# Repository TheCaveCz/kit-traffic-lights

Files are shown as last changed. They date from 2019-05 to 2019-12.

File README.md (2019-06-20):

# Traffic Lights / Semafory

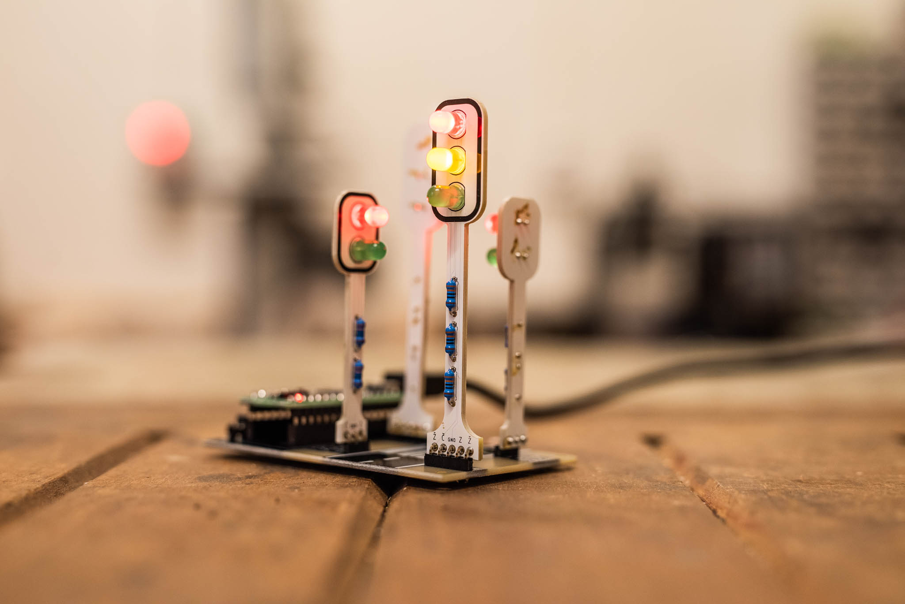
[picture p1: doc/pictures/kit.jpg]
kit


## Česky

Stavebnice přechodu pro chodce řízeného semafory. Tlačítko BTN1 dává signál pro chodce, tlačítko BTN3 vypne křižovatku.

* [Návod na stavbu](doc/manual-cz.md) ([PDF](doc/manual-cz.pdf))
* [Nahrání nového firmware](doc/firmware-cz.md)

## English

Coming coon...

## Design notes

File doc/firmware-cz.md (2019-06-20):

# Nahrání firmware

Arduina ve stavebnicích už mají program nahraný.

Kód je určený pro Arduino IDE. Pro nahrání do procesoru je nejprve potřeba nainstalovat knihovny [TaskScheduler](https://github.com/arkhipenko/TaskScheduler) a [OneButton](https://github.com/mathertel/OneButton).

Po nainstalování vyber v menu Tools (Nástroje) následující možnosti:

| Možnost | Hodnota |
| --- | --- |
| Board | Arduino Nano |
| Processor | ATmega328p |

Arduino připoj USB kabelem k počítači, vyber správný port a stiskni tlačítko upload.

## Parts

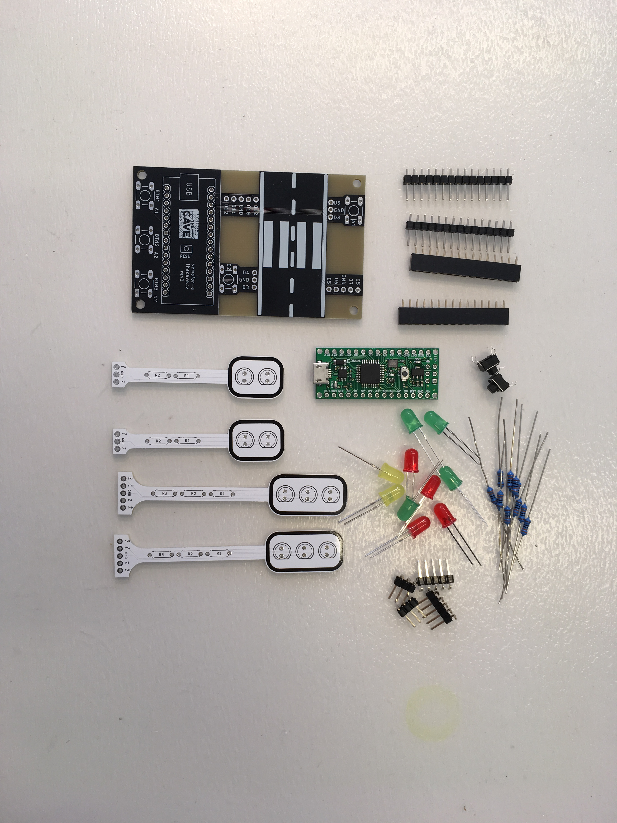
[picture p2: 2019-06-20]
doc/pictures/parts.jpg

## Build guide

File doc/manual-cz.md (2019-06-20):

# Návod na stavbu

[Stáhnout PDF](manual-cz.pdf)

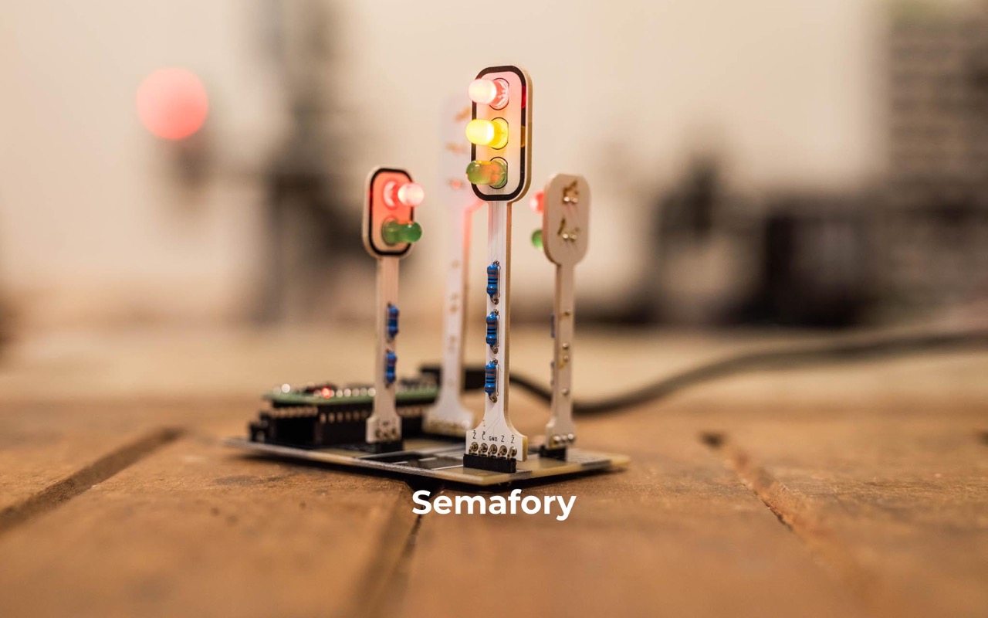
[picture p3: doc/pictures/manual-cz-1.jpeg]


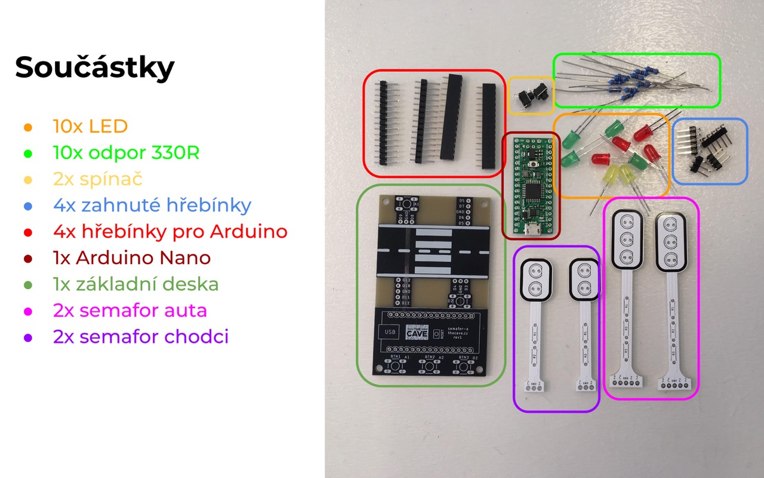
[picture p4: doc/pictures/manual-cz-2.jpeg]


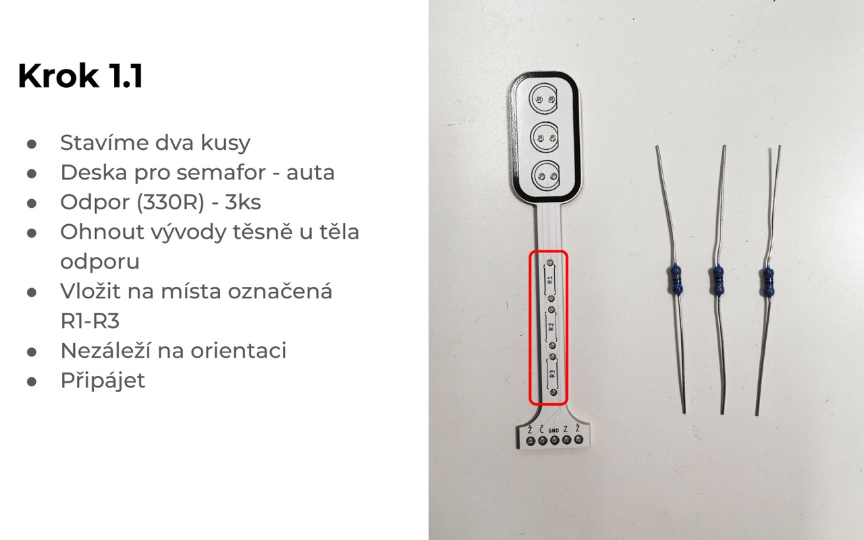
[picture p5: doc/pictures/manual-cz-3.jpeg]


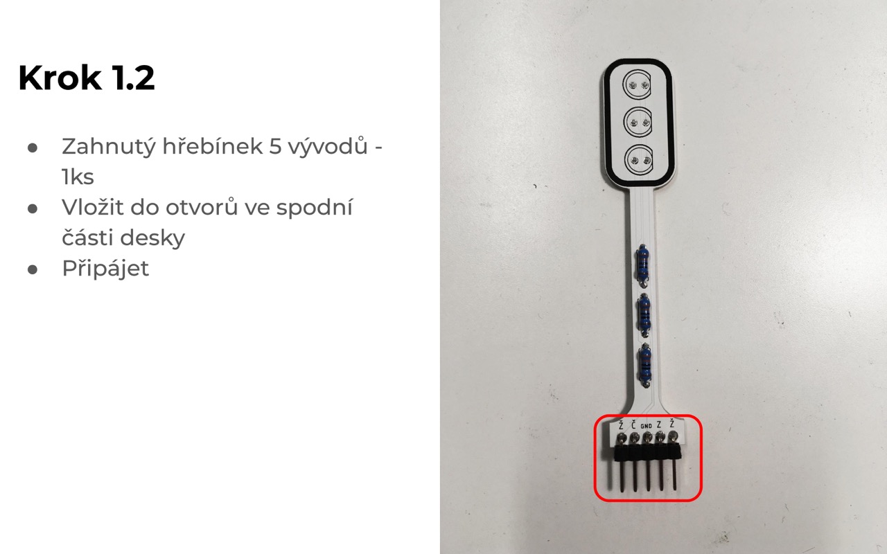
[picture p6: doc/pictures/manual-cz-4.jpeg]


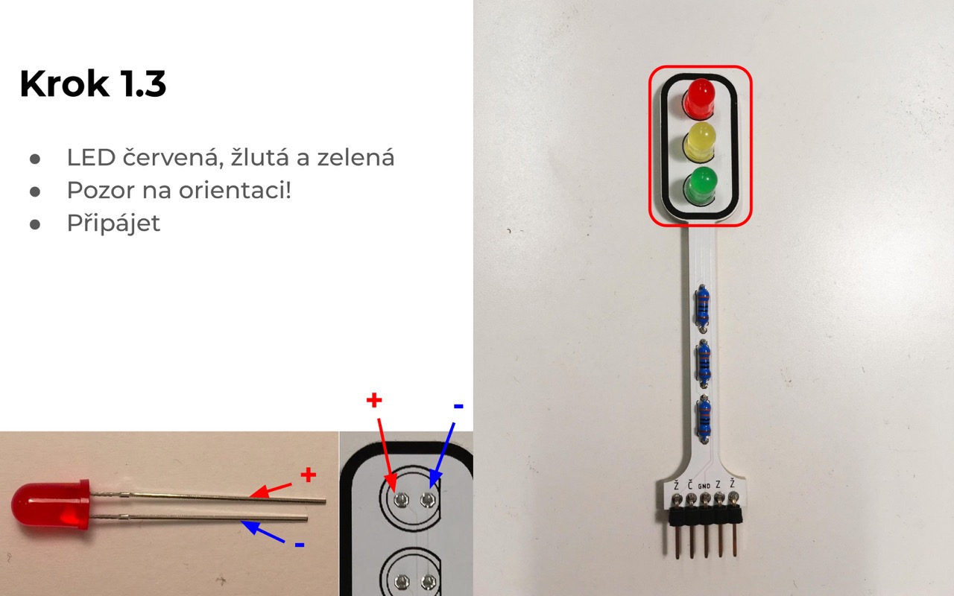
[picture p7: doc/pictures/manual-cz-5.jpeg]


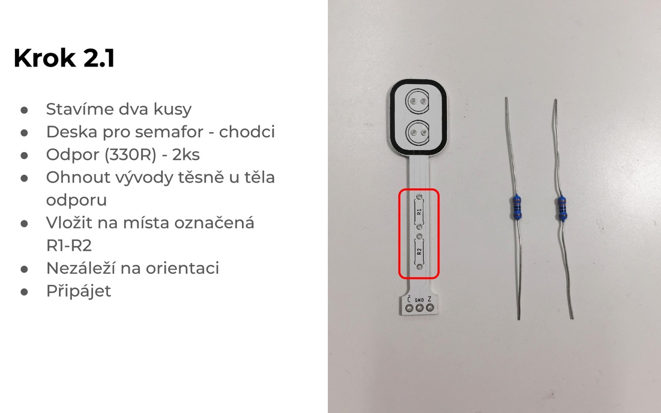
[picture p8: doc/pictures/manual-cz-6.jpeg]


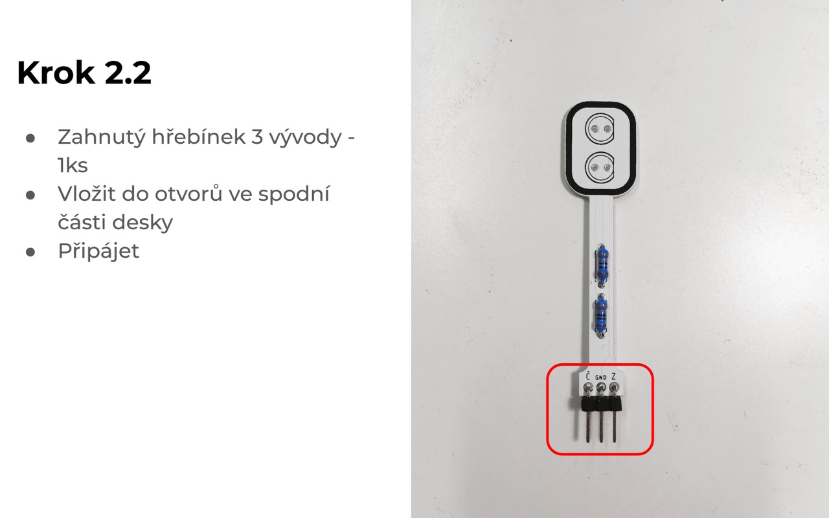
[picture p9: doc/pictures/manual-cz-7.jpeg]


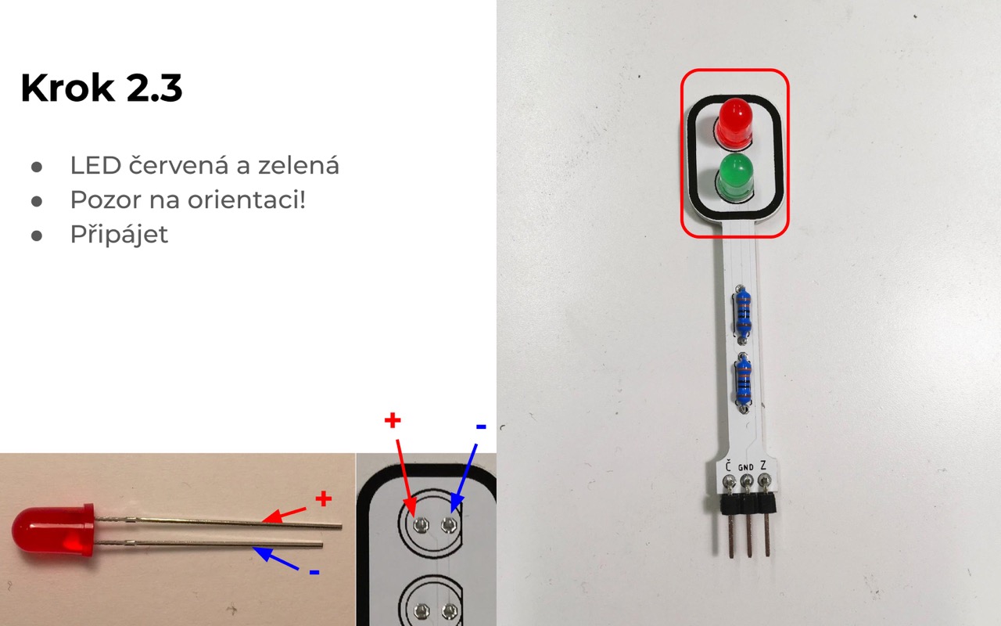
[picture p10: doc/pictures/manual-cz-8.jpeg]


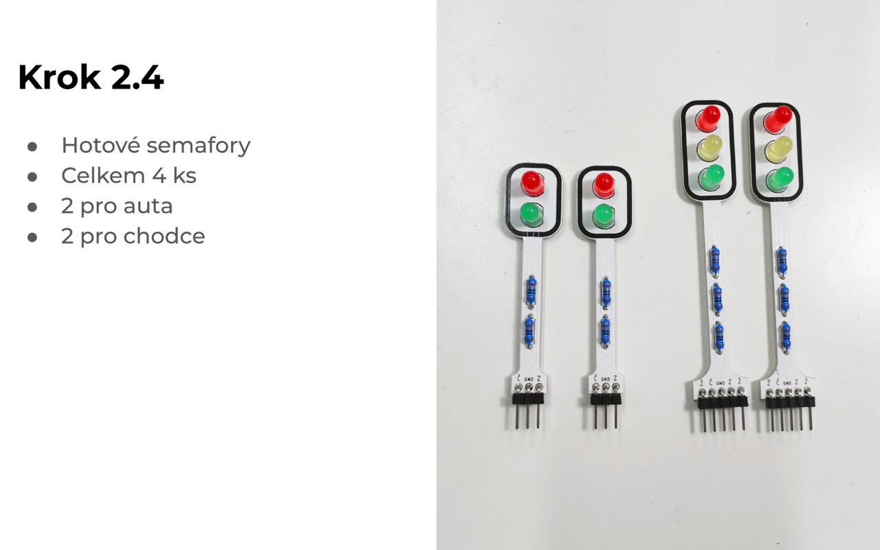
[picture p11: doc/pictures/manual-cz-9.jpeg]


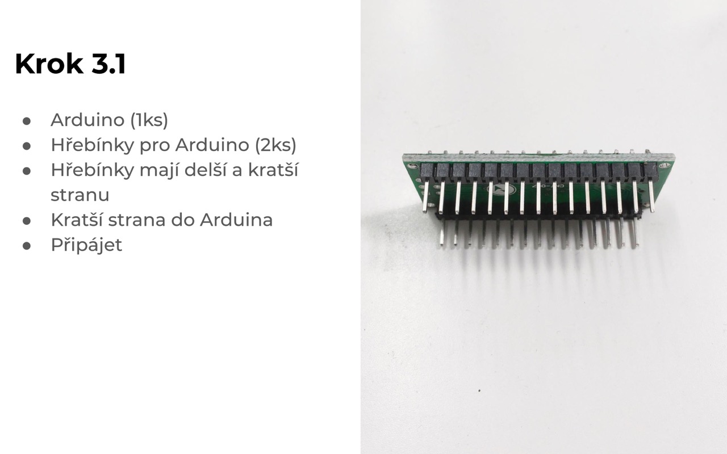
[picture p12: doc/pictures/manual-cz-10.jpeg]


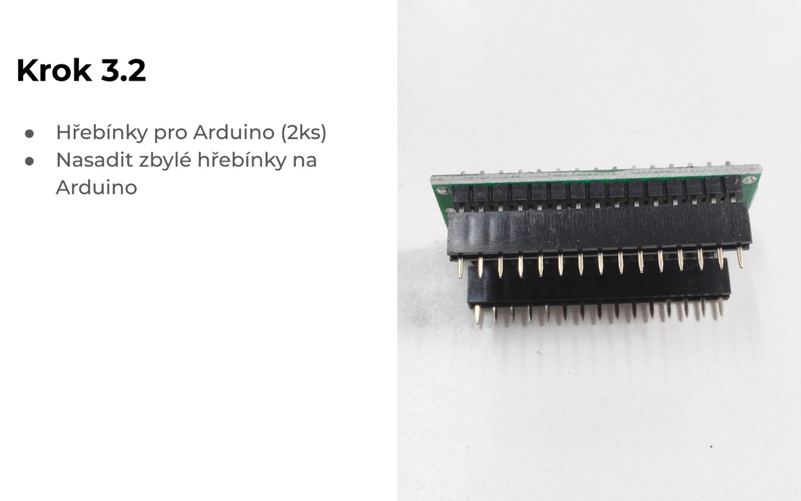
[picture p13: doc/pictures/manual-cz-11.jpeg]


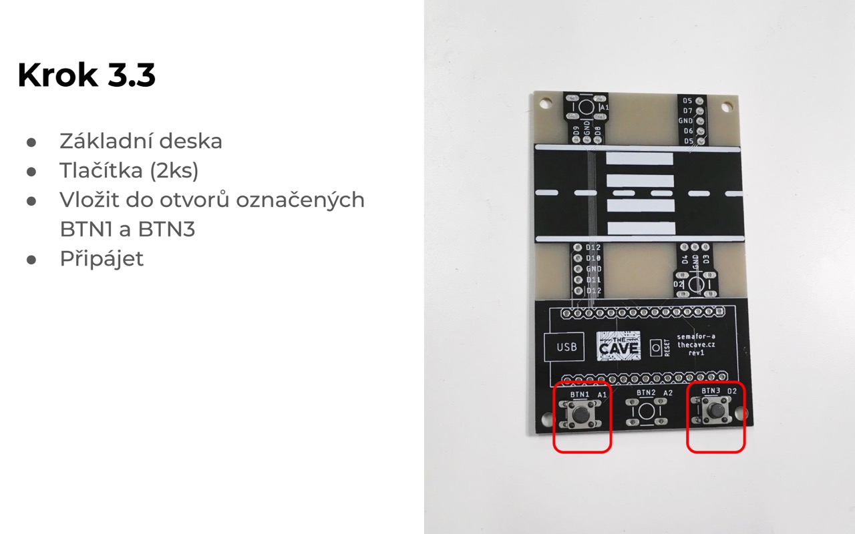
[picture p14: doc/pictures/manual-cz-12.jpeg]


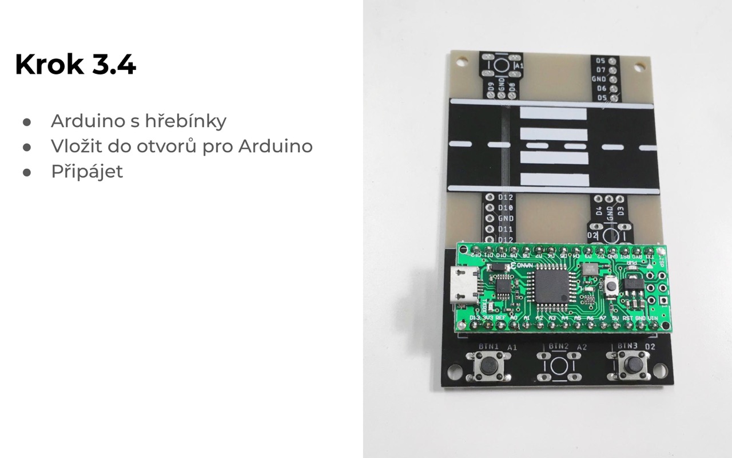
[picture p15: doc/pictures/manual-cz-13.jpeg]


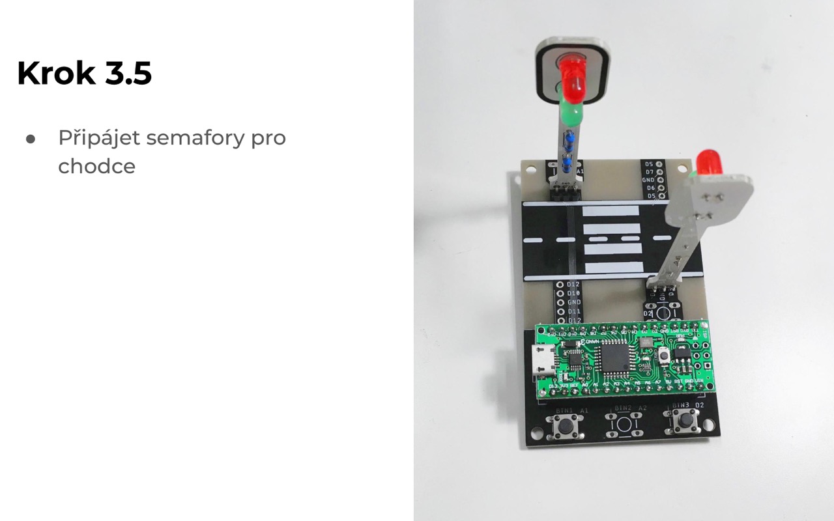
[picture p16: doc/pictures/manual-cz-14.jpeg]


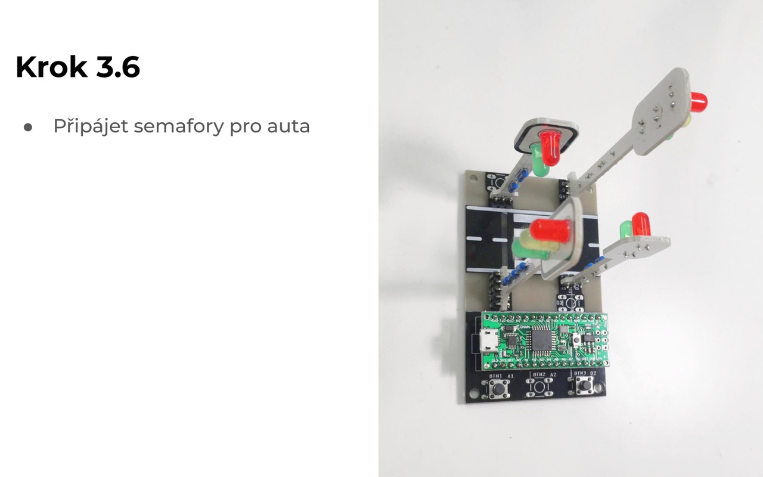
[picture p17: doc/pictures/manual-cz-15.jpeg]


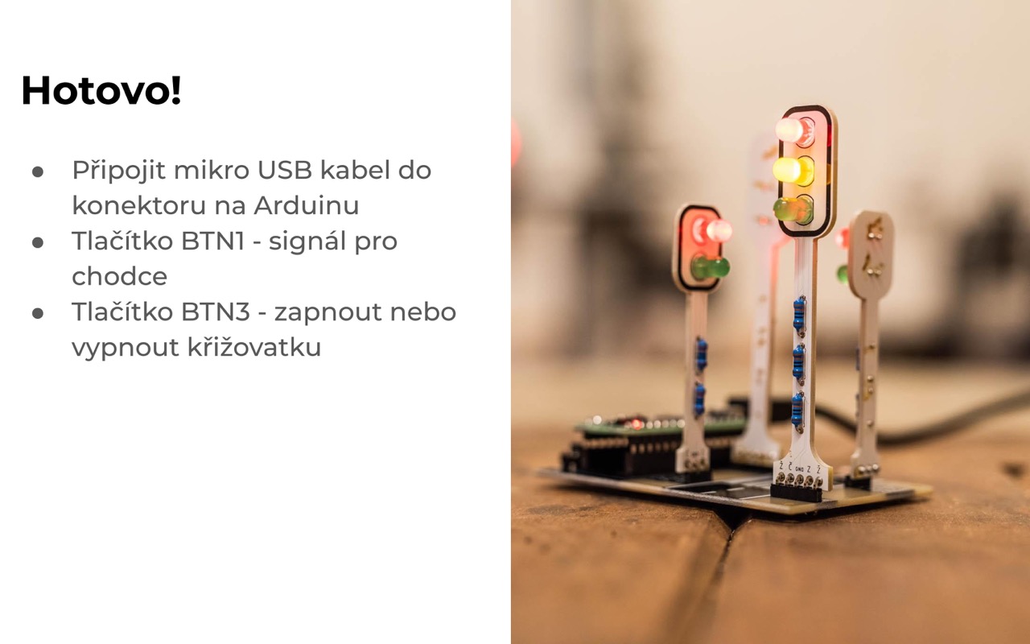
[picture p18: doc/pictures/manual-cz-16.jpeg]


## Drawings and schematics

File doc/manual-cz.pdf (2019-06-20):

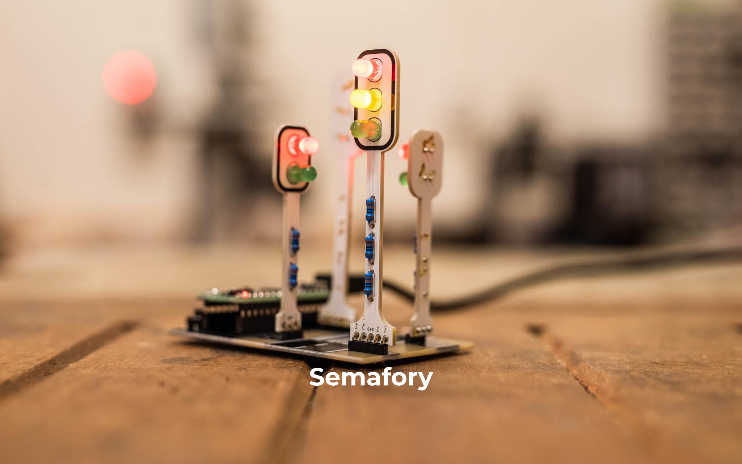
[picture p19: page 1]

Semafory

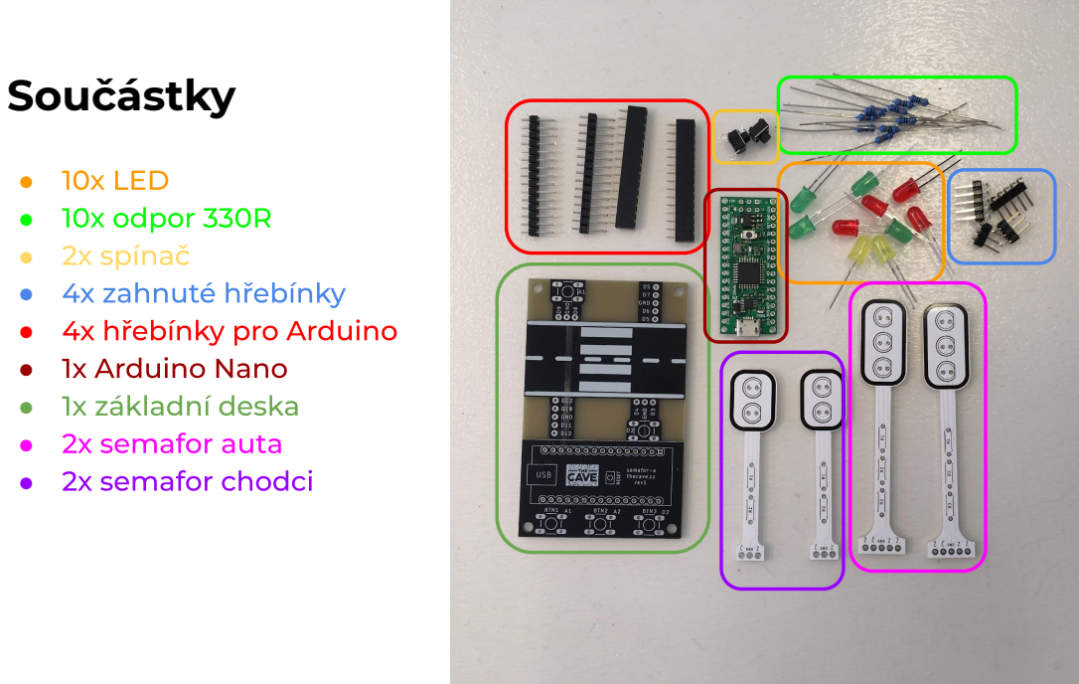
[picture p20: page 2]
Součástky

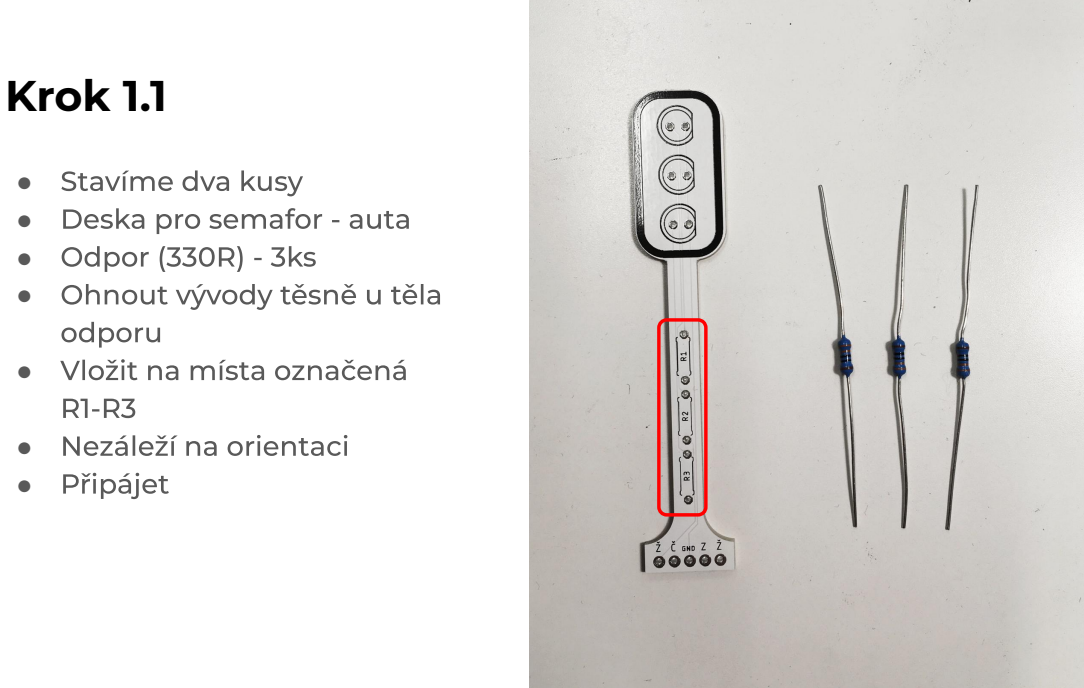
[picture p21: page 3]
Krok 1.1

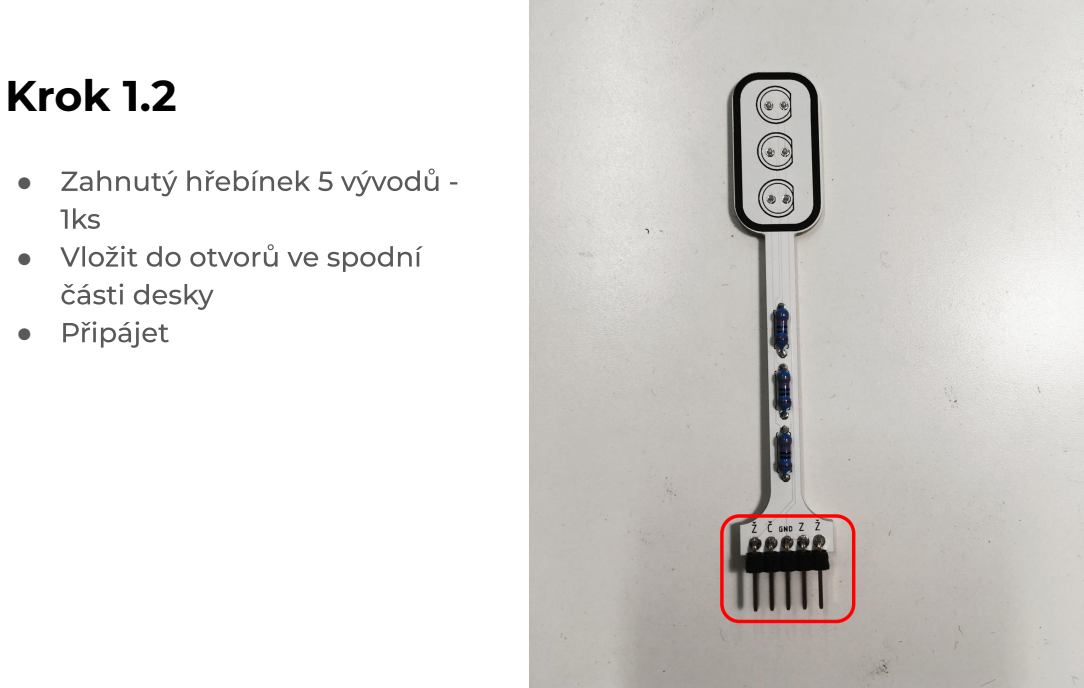
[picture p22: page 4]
Krok 1.2

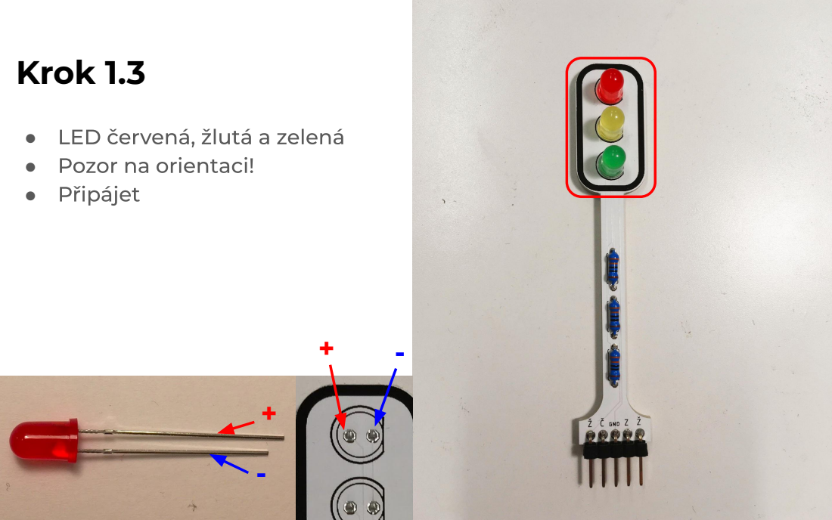
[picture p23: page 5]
Krok 1.3

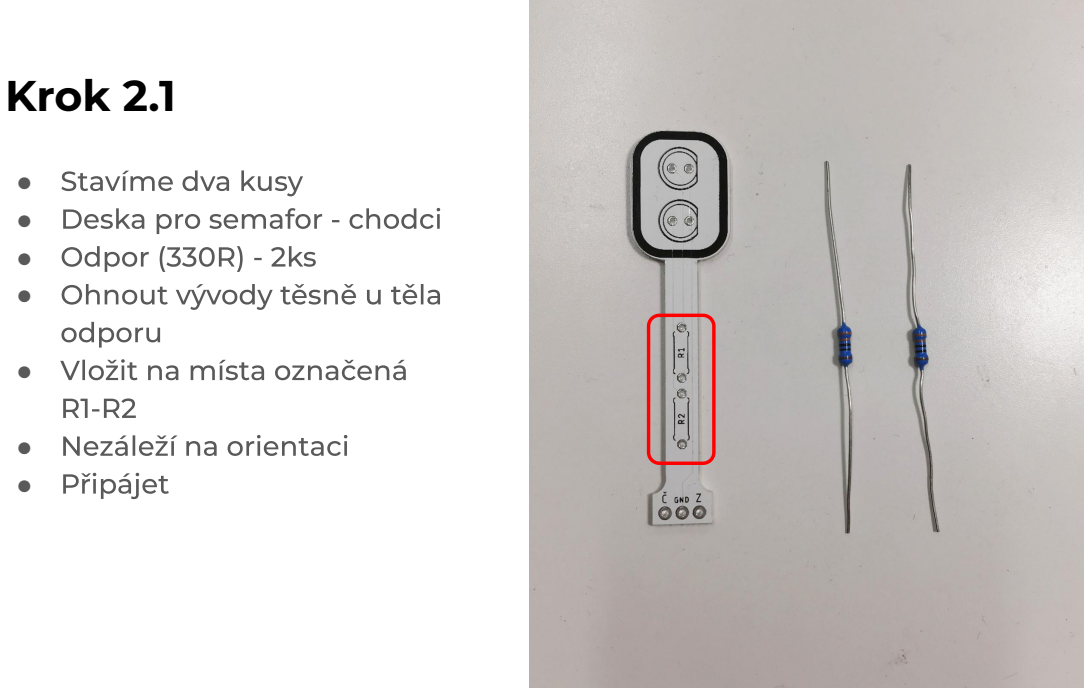
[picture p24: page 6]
Krok 2.1

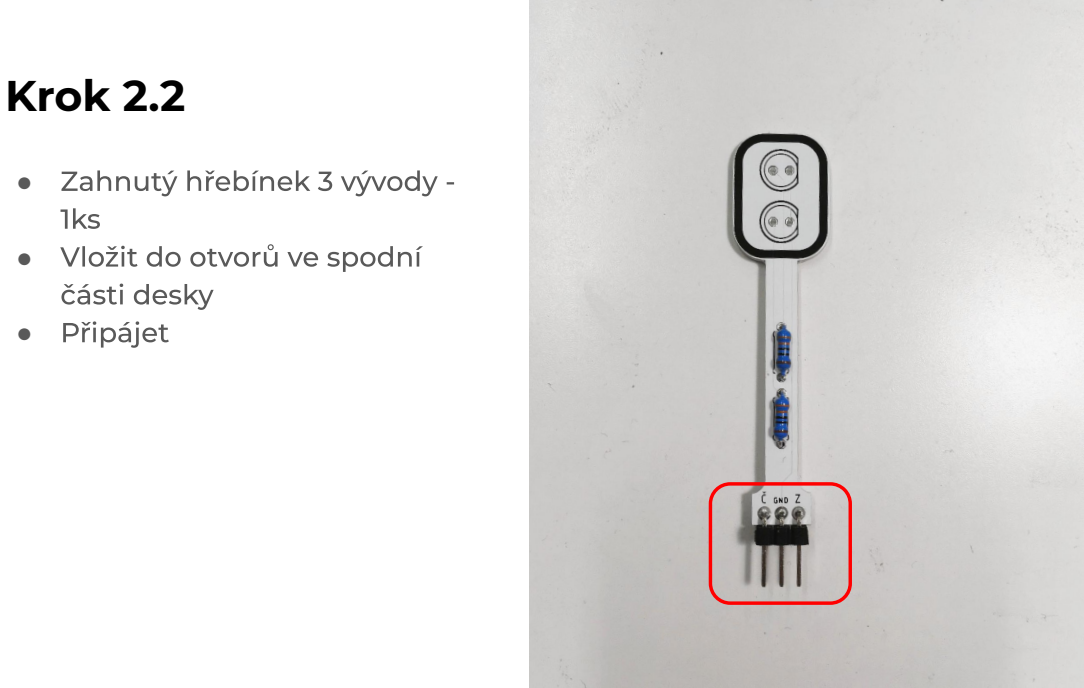
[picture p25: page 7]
Krok 2.2

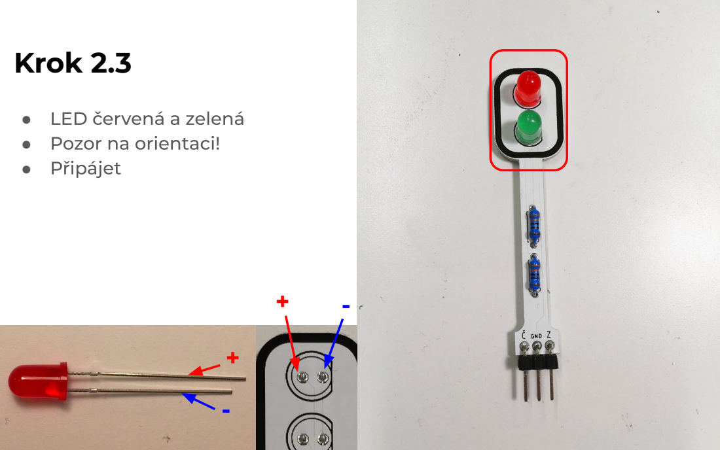
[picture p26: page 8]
Krok 2.3

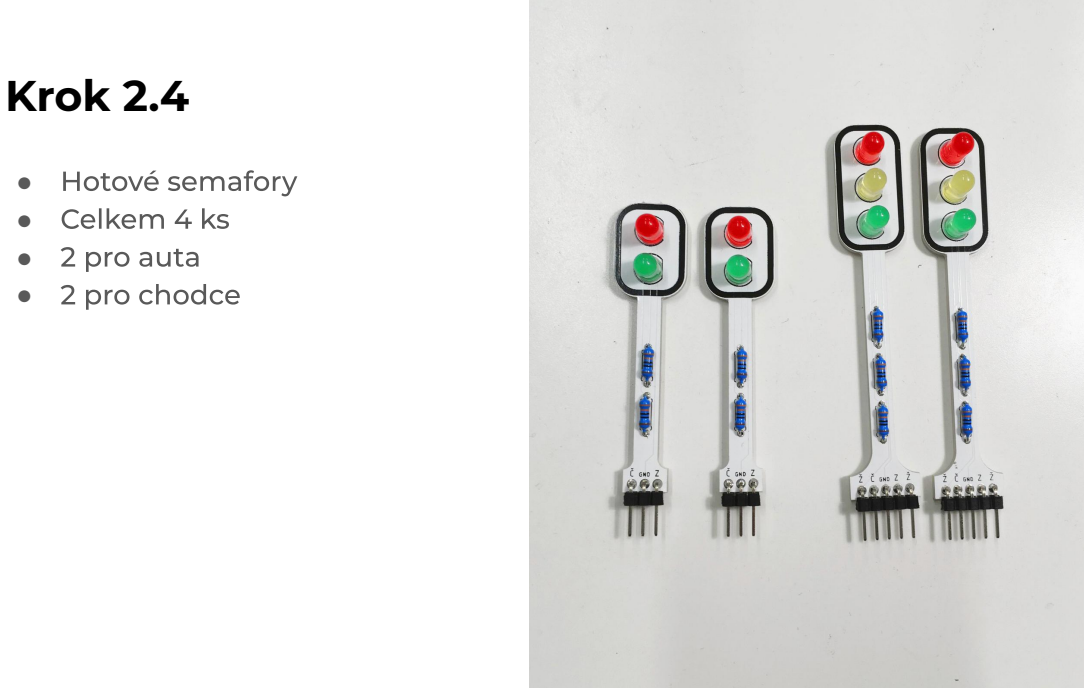
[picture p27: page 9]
Krok 2.4

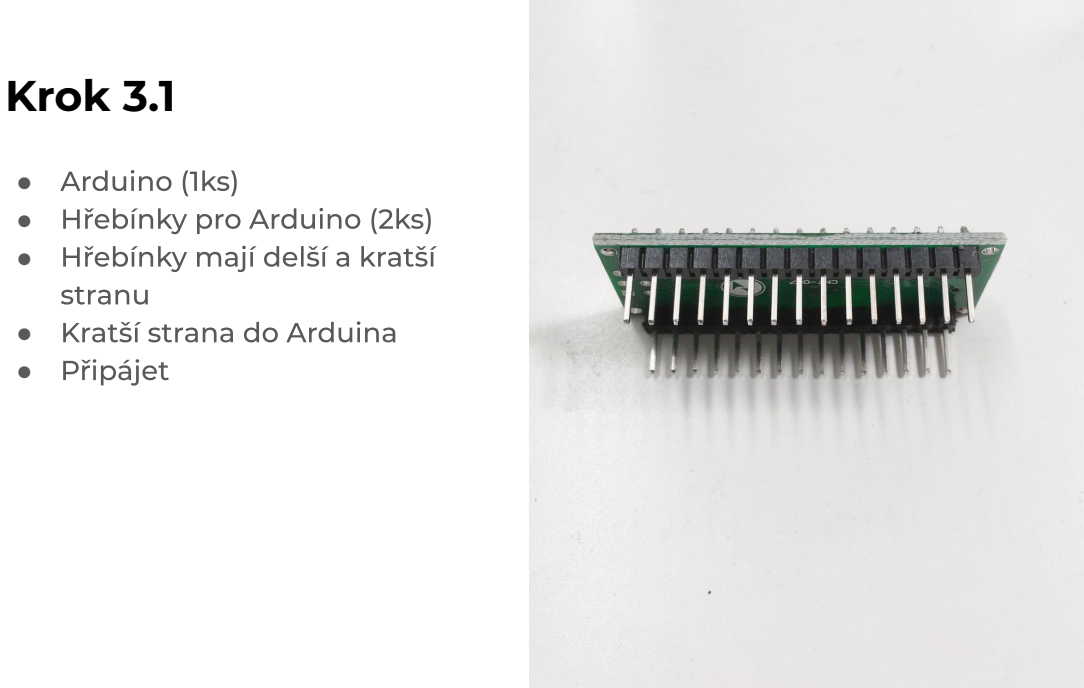
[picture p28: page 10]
Krok 3.1

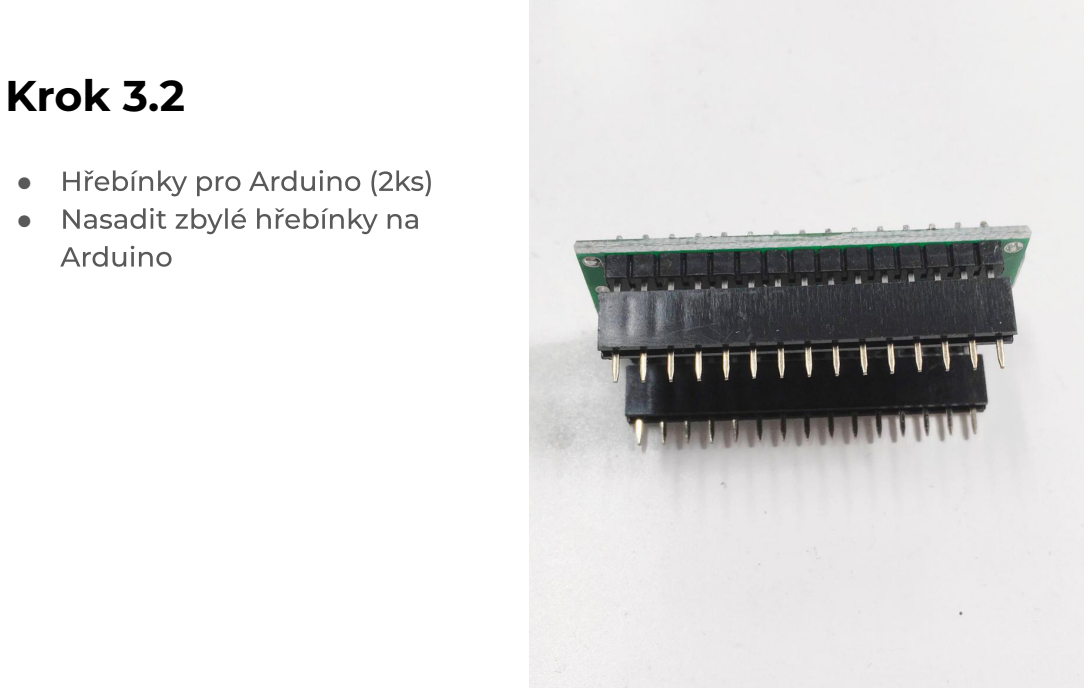
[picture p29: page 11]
Krok 3.2

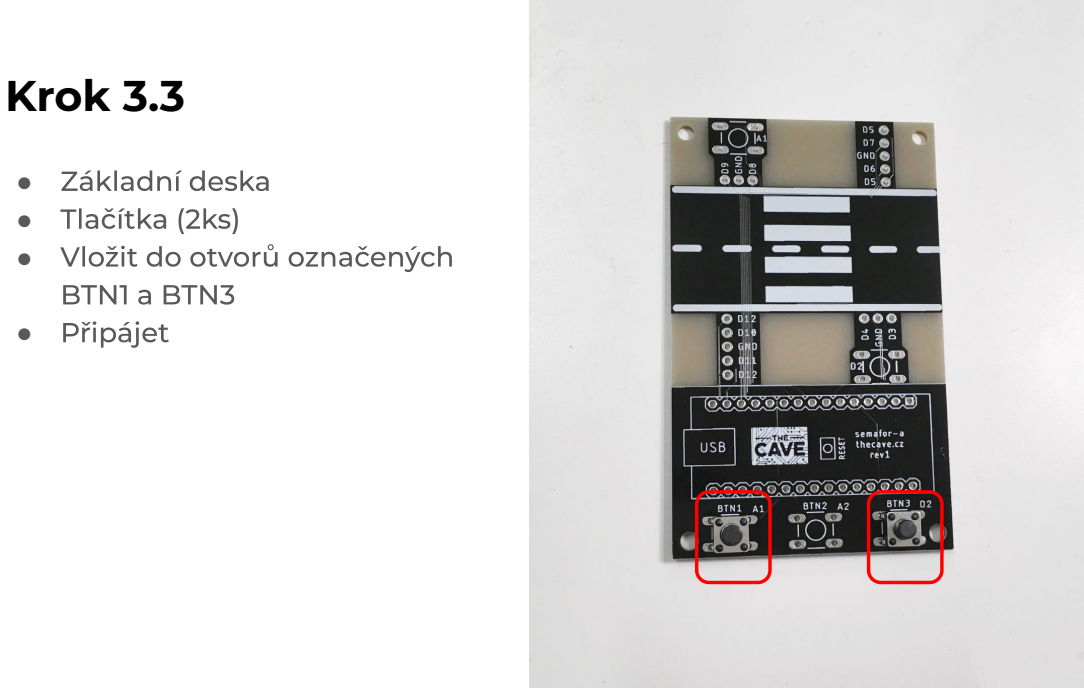
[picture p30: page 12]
Krok 3.3

Krok 3.4

Krok 3.5

Krok 3.6

Hotovo!


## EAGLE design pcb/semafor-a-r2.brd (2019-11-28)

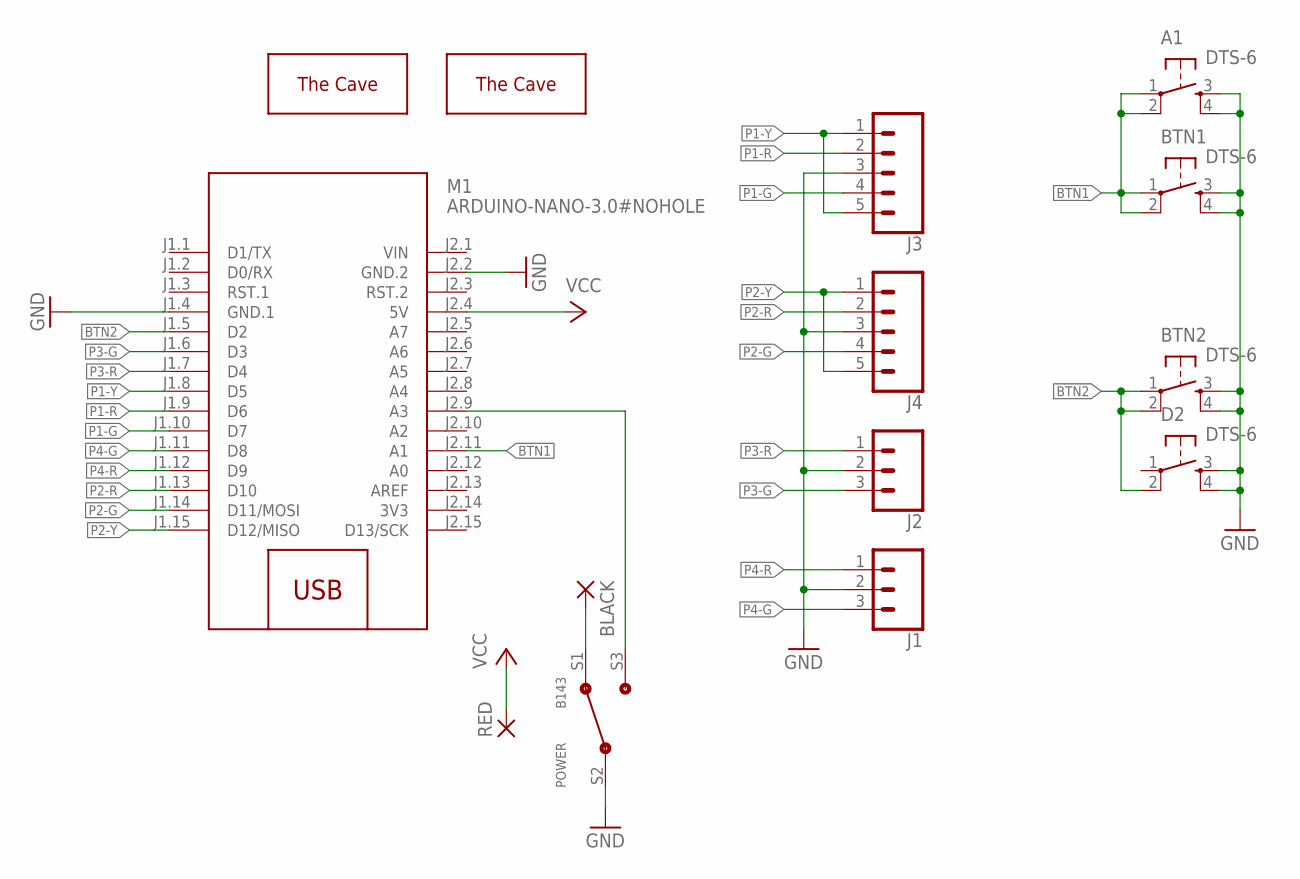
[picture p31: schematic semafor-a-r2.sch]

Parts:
A1: DTS-6
BLACK: WIREPAD2,54/1,0; 2,54/1,0
BTN1, BTN2: DTS-6
D2: DTS-6
J1, J2: CONN_031X03_NO_SILK; 1X03_NO_SILK
J3, J4: CONN_05NO_SILK; 1X05_NO_SILK
M1: ARDUINO-NANO-3.0#NOHOLE; ARDUINO-NANO-3.0
POWER: B143
RED: WIREPAD2,54/1,0; 2,54/1,0
U$1: THECAVE_LOGO_NEW_TOP_SMALL; NEW_LOGO_SMALL_TOP
U$2: THECAVE_LOGO_NEW_BOTTOM; NEW_LOGO_BOTTOM

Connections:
3V3: M1.J2.14 (3V3)
BTN1: A1.1, A1.2, BTN1.1, BTN1.2, M1.J2.11 (A1)
BTN2: BTN2.1, BTN2.2, D2.2, M1.J1.5 (D2)
GND: A1.3, A1.4, BTN1.3, BTN1.4, BTN2.3, BTN2.4, D2.3, D2.4, J1.2, J2.2, J3.3, J4.3, M1.J1.4 (GND.1), M1.J2.2 (GND.2), POWER.S2 (COM)
unnamed: M1.J2.9 (A3), POWER.S3 (S2)
unnamed: BLACK.1, POWER.S1
P1-G: J3.4, M1.J1.10 (D7)
P1-R: J3.2, M1.J1.9 (D6)
P1-Y: J3.1, J3.5, M1.J1.8 (D5)
P2-G: J4.4, M1.J1.14 (D11/MOSI)
P2-R: J4.2, M1.J1.13 (D10)
P2-Y: J4.1, J4.5, M1.J1.15 (D12/MISO)
P3-G: J2.3, M1.J1.6 (D3)
P3-R: J2.1, M1.J1.7 (D4)
P4-G: J1.3, M1.J1.11 (D8)
P4-R: J1.1, M1.J1.12 (D9)
VCC: M1.J2.4 (5V), RED.1
VIN: M1.J2.1 (VIN)

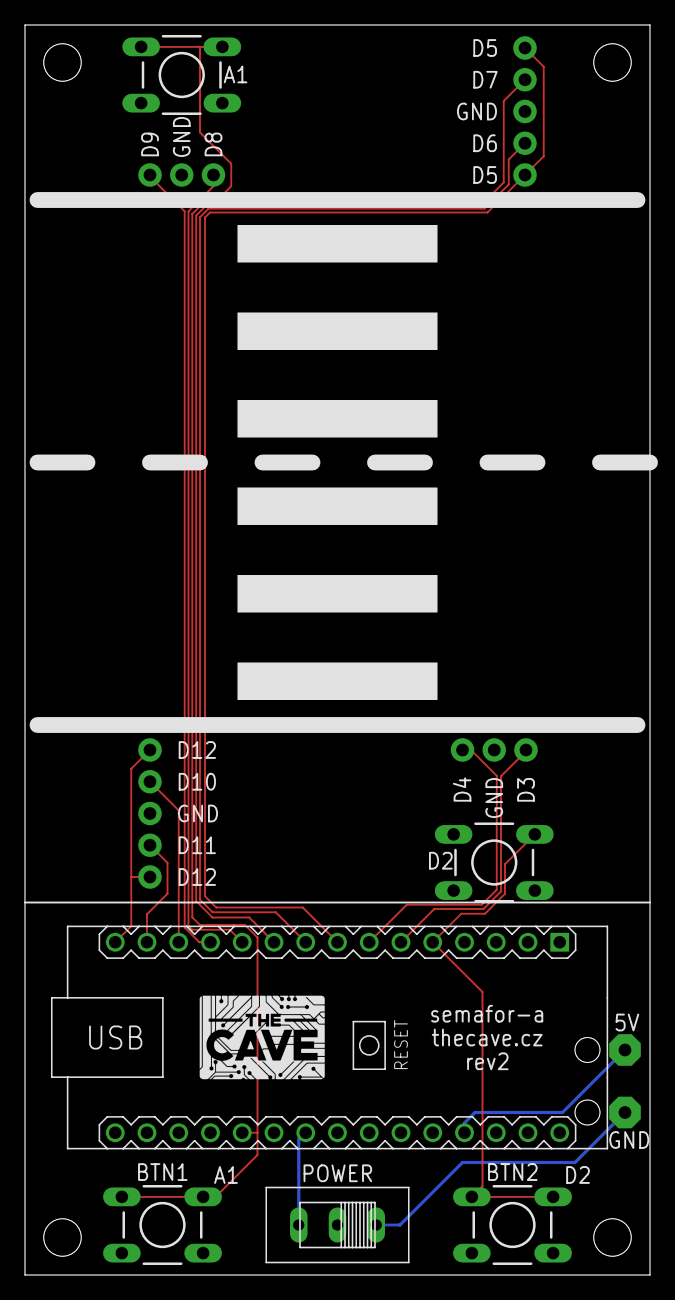
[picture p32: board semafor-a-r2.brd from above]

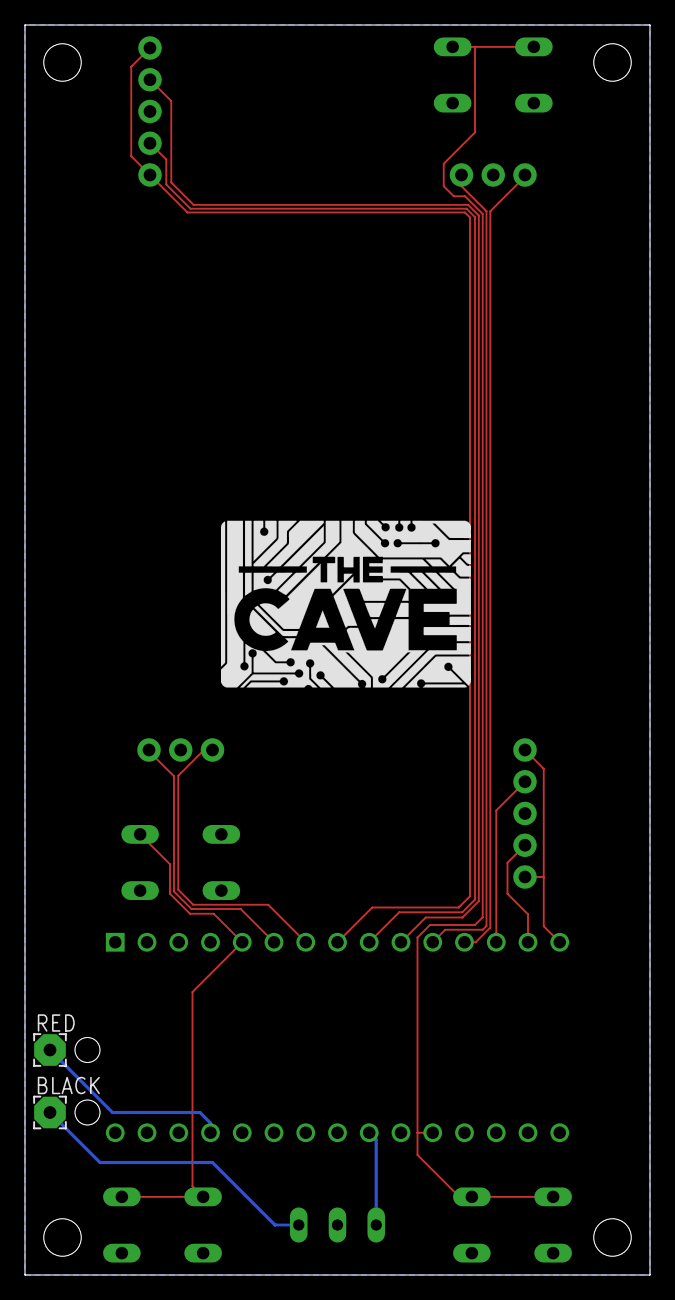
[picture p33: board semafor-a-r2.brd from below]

Board: 2 copper layers, 50.0 x 100.0 mm, 14 parts (2 on the bottom side), 16 nets.

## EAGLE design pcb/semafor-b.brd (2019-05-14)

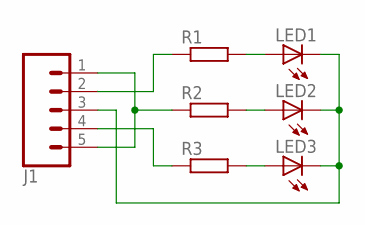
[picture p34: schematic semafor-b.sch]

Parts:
J1: CONN_05NO_SILK; 1X05_NO_SILK
LED1, LED2, LED3: LED5MM
R1, R2, R3: R-EU_0207/7; 0207/7

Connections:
unnamed: LED3.A, R3.2
unnamed: LED2.A, R2.2
unnamed: LED1.A, R1.2
unnamed: J1.3, LED1.K (C), LED2.K (C), LED3.K (C)
unnamed: J1.2, R1.1
unnamed: J1.4, R3.1
unnamed: J1.1, J1.5, R2.1

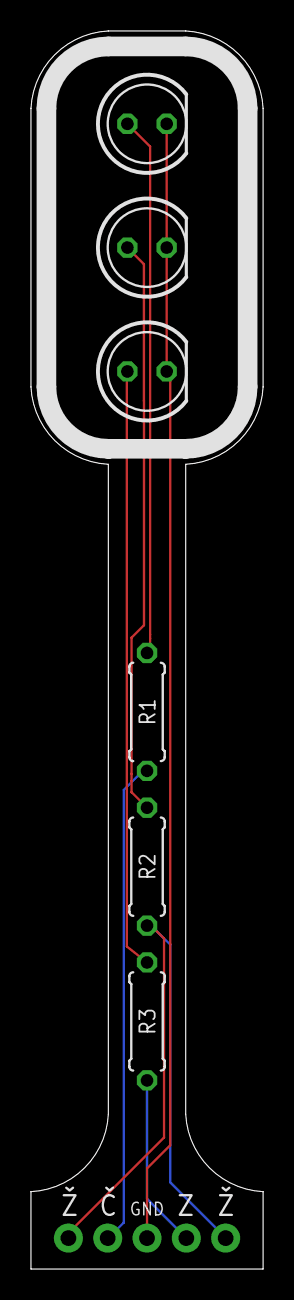
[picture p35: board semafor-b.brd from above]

Board: 2 copper layers, 15.0 x 80.0 mm, 7 parts (0 on the bottom side), 7 nets.

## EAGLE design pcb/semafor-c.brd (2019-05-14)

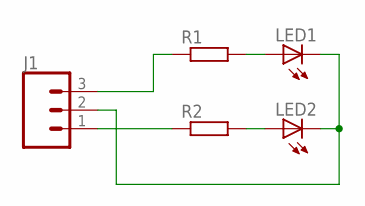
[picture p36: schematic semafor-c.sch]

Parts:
J1: CONN_031X03_NO_SILK; 1X03_NO_SILK
LED1, LED2: LED5MM
R1, R2: R-EU_0207/7; 0207/7

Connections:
unnamed: LED2.A, R2.2
unnamed: LED1.A, R1.2
unnamed: J1.2, LED1.K (C), LED2.K (C)
unnamed: J1.3, R1.1
unnamed: J1.1, R2.1

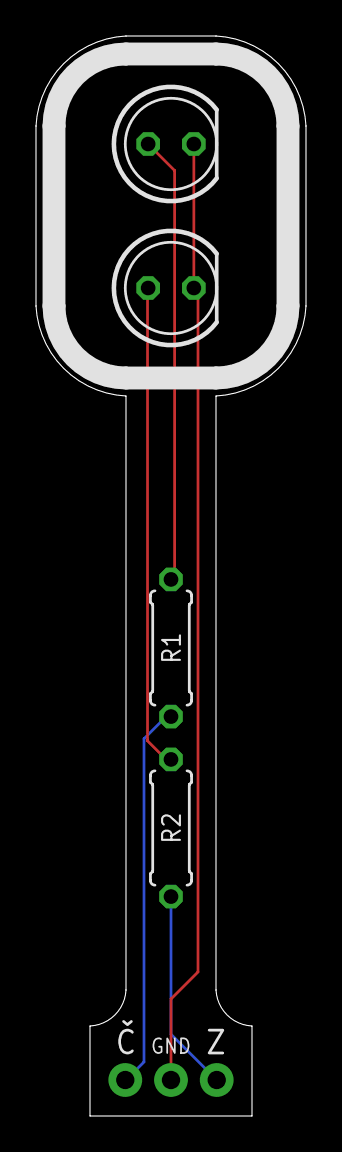
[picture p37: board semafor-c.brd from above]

Board: 2 copper layers, 15.0 x 60.0 mm, 5 parts (0 on the bottom side), 5 nets.

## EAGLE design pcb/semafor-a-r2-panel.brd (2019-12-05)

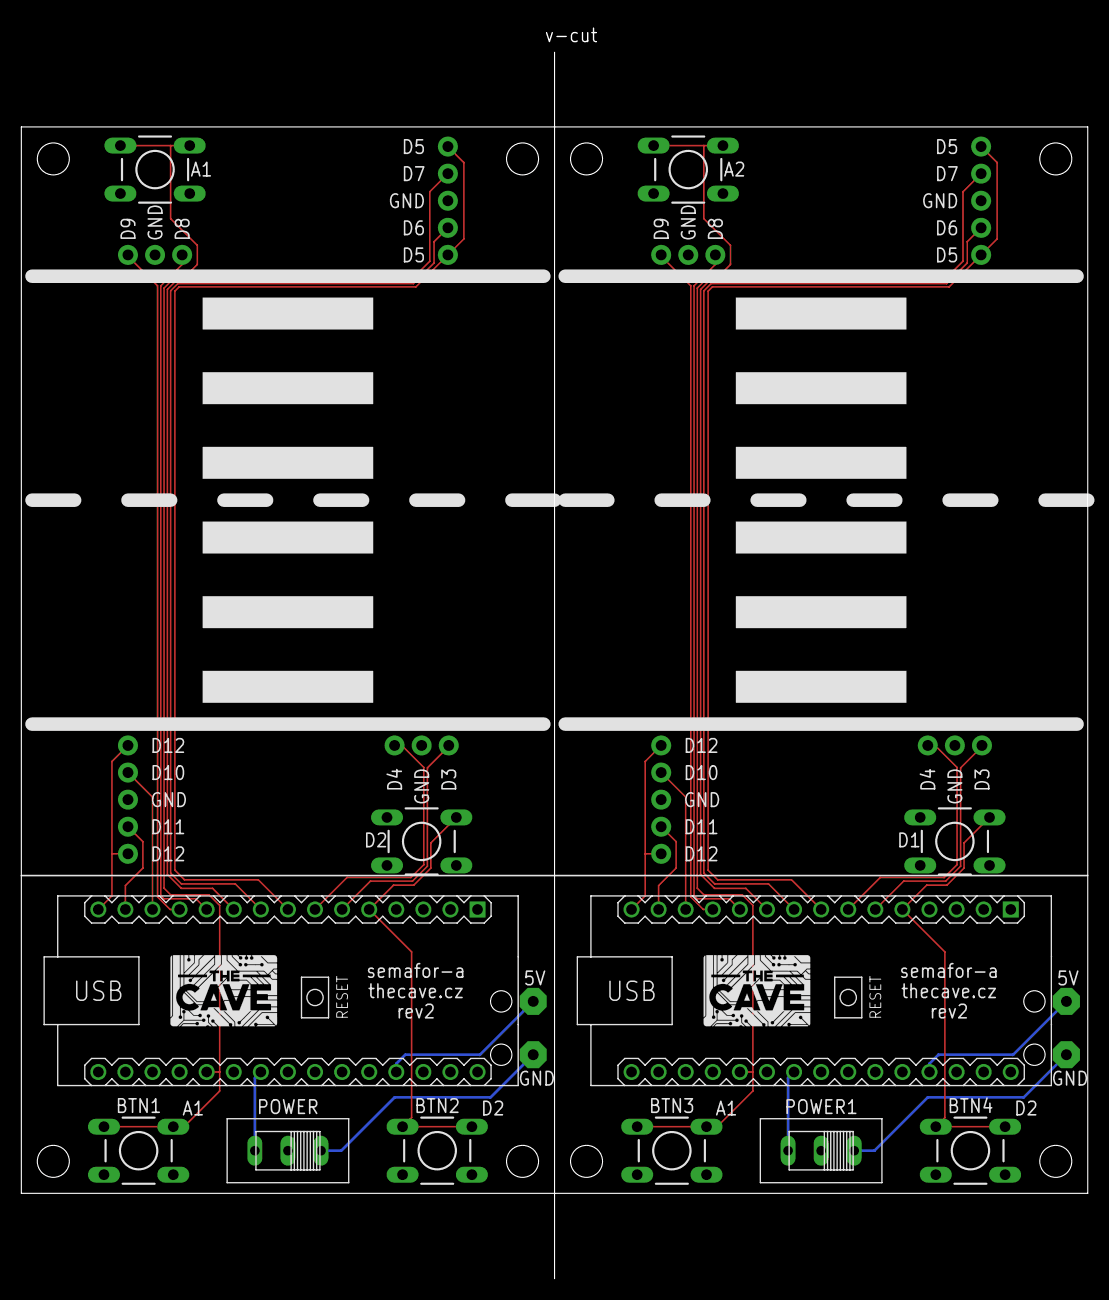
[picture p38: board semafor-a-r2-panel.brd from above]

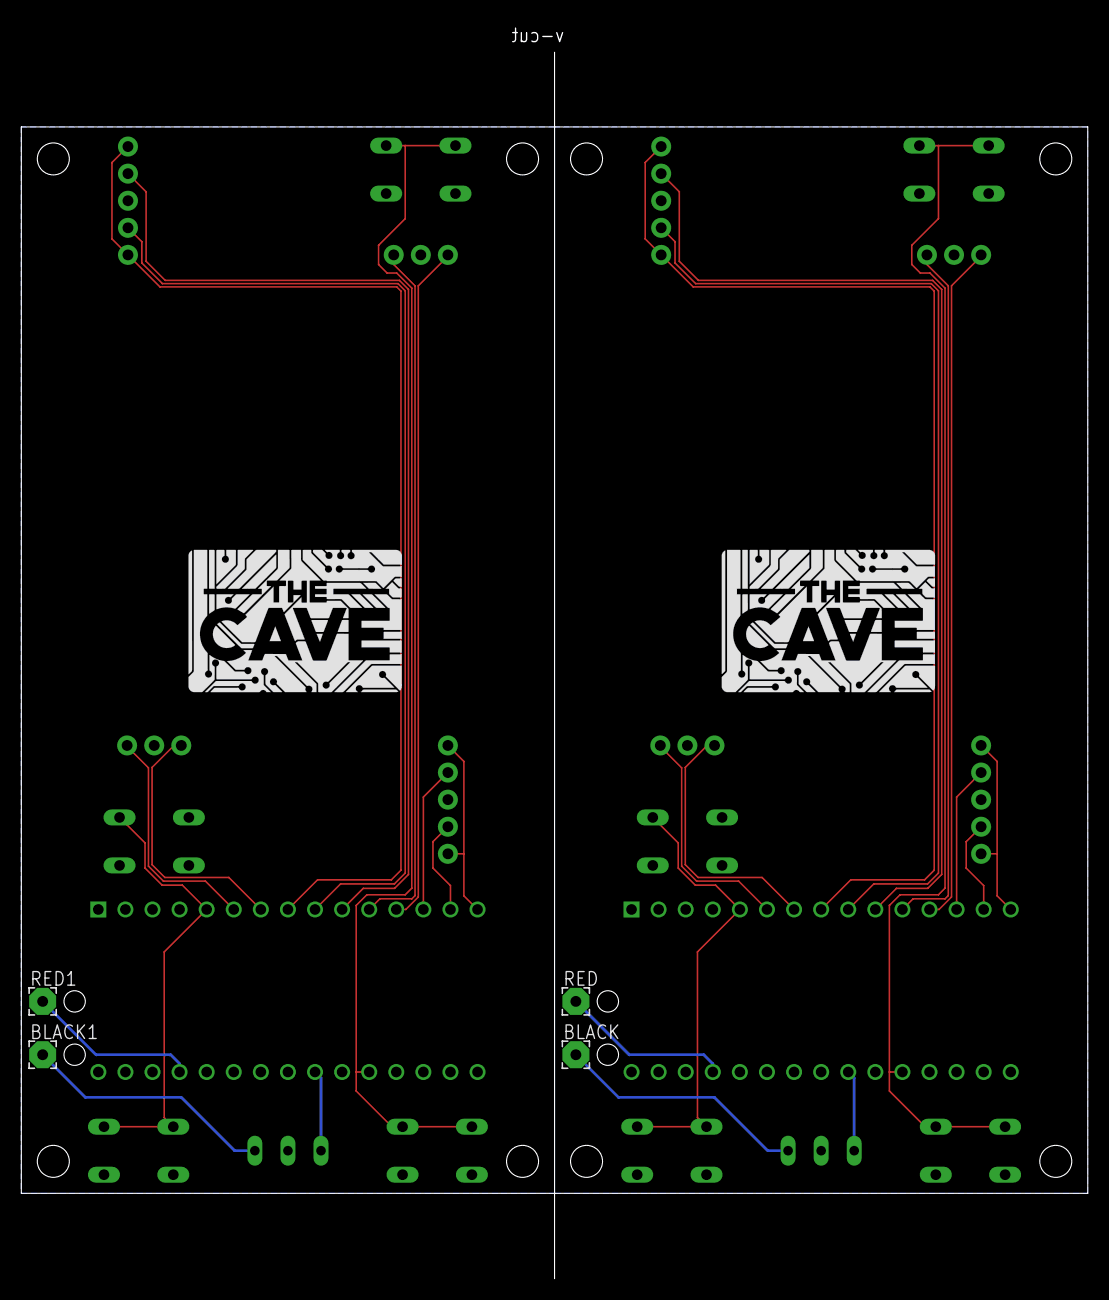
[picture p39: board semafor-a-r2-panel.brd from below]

Board: 2 copper layers, 100.0 x 100.0 mm, 28 parts (4 on the bottom side), 32 nets.

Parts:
A1, A2: DTS-6
BLACK, BLACK1: 2,54/1,0
BTN1, BTN2, BTN3, BTN4: DTS-6
D1, D2: DTS-6
J1, J2, J5, J6: 1X03_NO_SILK
J3, J4, J7, J8: 1X05_NO_SILK
M1, M2: ARDUINO-NANO-3.0#NOHOLE; ARDUINO-NANO-3.0
POWER, POWER1: B143
RED, RED1: 2,54/1,0
U$1, U$3: THECAVE_LOGO_NEW_TOP_SMALL; NEW_LOGO_SMALL_TOP
U$2, U$4: THECAVE_LOGO_NEW_BOTTOM; NEW_LOGO_BOTTOM

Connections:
BTN1: A1.1, A1.2, BTN1.1, BTN1.2, M1.J2.11
BTN2: BTN2.1, BTN2.2, D2.2, M1.J1.5
BTN3: A2.1, A2.2, BTN3.1, BTN3.2, M2.J2.11
BTN4: BTN4.1, BTN4.2, D1.2, M2.J1.5
GND: A1.3, A1.4, BTN1.3, BTN1.4, BTN2.3, BTN2.4, D2.3, D2.4, J1.2, J2.2, J3.3, J4.3, M1.J1.4, M1.J2.2, POWER.S2
GND1: A2.3, A2.4, BTN3.3, BTN3.4, BTN4.3, BTN4.4, D1.3, D1.4, J5.2, J6.2, J7.3, J8.3, M2.J1.4, M2.J2.2, POWER1.S2
unnamed: M1.J2.9, POWER.S3
unnamed: BLACK.1, POWER.S1
unnamed: M2.J2.9, POWER1.S3
unnamed: BLACK1.1, POWER1.S1
P1-G: J3.4, M1.J1.10
P1-G1: J7.4, M2.J1.10
P1-R: J3.2, M1.J1.9
P1-R1: J7.2, M2.J1.9
P1-Y: J3.1, J3.5, M1.J1.8
P1-Y1: J7.1, J7.5, M2.J1.8
P2-G: J4.4, M1.J1.14
P2-G1: J8.4, M2.J1.14
P2-R: J4.2, M1.J1.13
P2-R1: J8.2, M2.J1.13
P2-Y: J4.1, J4.5, M1.J1.15
P2-Y1: J8.1, J8.5, M2.J1.15
P3-G: J2.3, M1.J1.6
P3-G1: J6.3, M2.J1.6
P3-R: J2.1, M1.J1.7
P3-R1: J6.1, M2.J1.7
P4-G: J1.3, M1.J1.11
P4-G1: J5.3, M2.J1.11
P4-R: J1.1, M1.J1.12
P4-R1: J5.1, M2.J1.12
VCC: M1.J2.4, RED.1
VCC1: M2.J2.4, RED1.1

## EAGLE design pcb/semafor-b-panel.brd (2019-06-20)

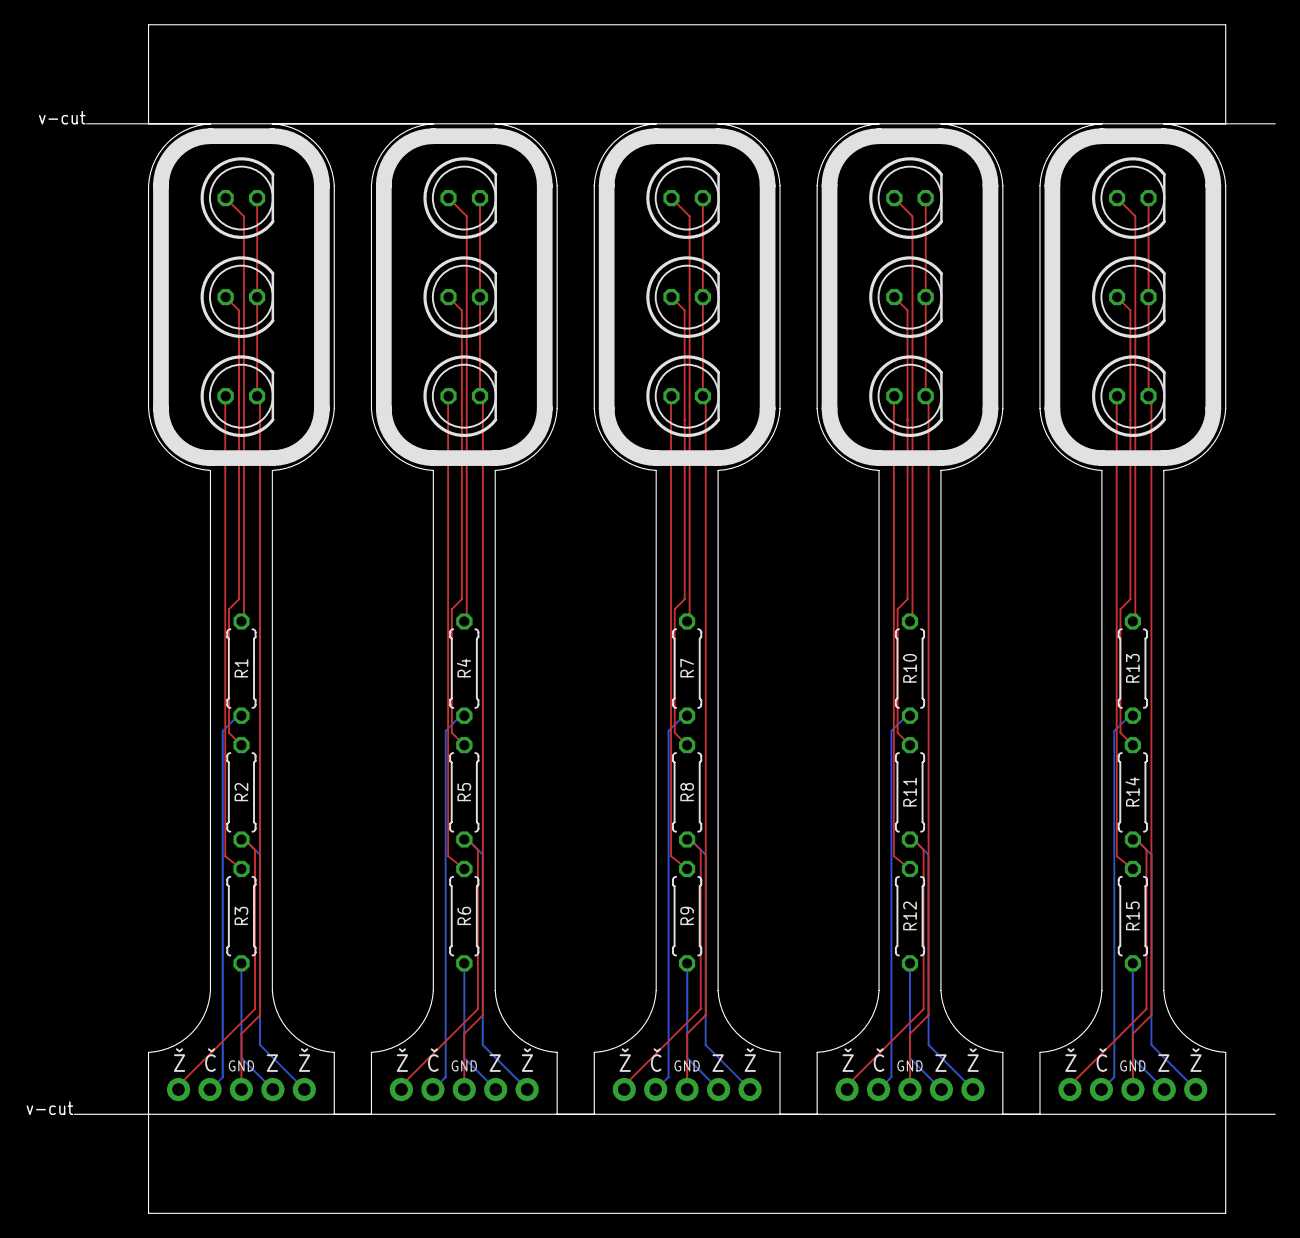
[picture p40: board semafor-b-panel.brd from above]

Board: 2 copper layers, 87.0 x 96.0 mm, 35 parts (0 on the bottom side), 35 nets.

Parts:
J1, J2, J3, J4, J5: 1X05_NO_SILK
LED1, LED2, LED3, LED4, LED5, LED6, LED7, LED8, LED9, LED10, LED11, LED12, LED13, LED14, LED15: LED5MM
R1, R2, R3, R4, R5, R6, R7, R8, R9, R10, R11, R12, R13, R14, R15: 0207/7

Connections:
unnamed: LED3.A, R3.2
unnamed: LED2.A, R2.2
unnamed: LED1.A, R1.2
unnamed: J1.3, LED1.K, LED2.K, LED3.K
unnamed: J1.2, R1.1
unnamed: J1.4, R3.1
unnamed: J1.1, J1.5, R2.1
unnamed: J2.3, LED4.K, LED5.K, LED6.K
unnamed: J2.2, R4.1
unnamed: J2.4, R6.1
unnamed: J2.1, J2.5, R5.1
unnamed: LED6.A, R6.2
unnamed: LED5.A, R5.2
unnamed: LED4.A, R4.2
unnamed: J3.3, LED7.K, LED8.K, LED9.K
unnamed: J3.2, R7.1
unnamed: J3.4, R9.1
unnamed: J3.1, J3.5, R8.1
unnamed: LED9.A, R9.2
unnamed: LED8.A, R8.2
unnamed: LED7.A, R7.2
unnamed: J4.3, LED10.K, LED11.K, LED12.K
unnamed: J4.2, R10.1
unnamed: J4.4, R12.1
unnamed: J4.1, J4.5, R11.1
unnamed: LED12.A, R12.2
unnamed: LED11.A, R11.2
unnamed: LED10.A, R10.2
unnamed: J5.3, LED13.K, LED14.K, LED15.K
unnamed: J5.2, R13.1
unnamed: J5.4, R15.1
unnamed: J5.1, J5.5, R14.1
unnamed: LED15.A, R15.2
unnamed: LED14.A, R14.2
unnamed: LED13.A, R13.2

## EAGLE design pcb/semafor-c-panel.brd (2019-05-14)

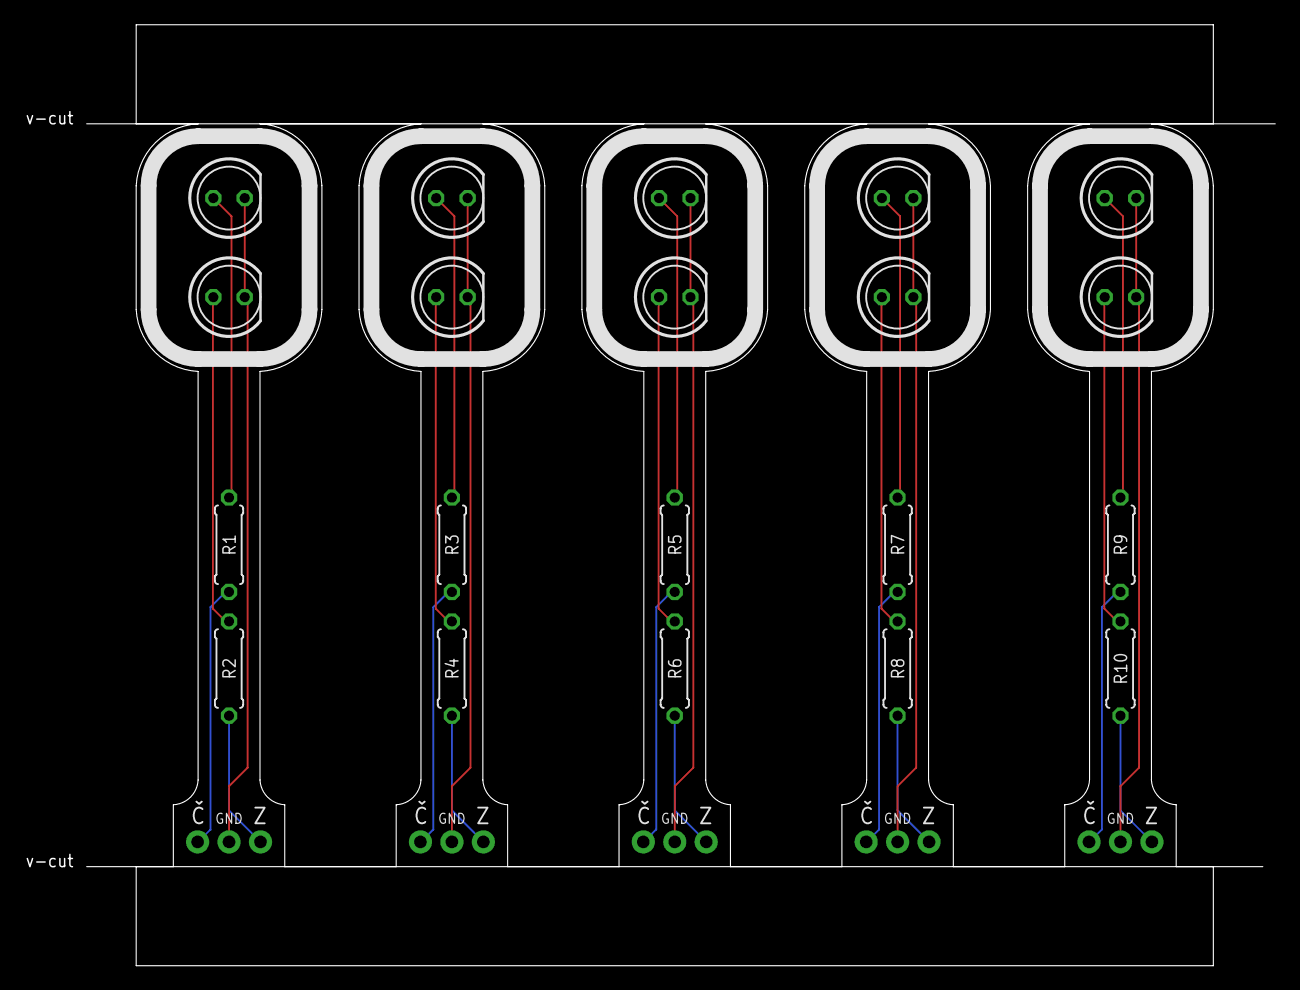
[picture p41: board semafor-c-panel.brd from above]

Board: 2 copper layers, 87.0 x 76.0 mm, 25 parts (0 on the bottom side), 25 nets.

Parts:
J1, J2, J3, J4, J5: 1X03_NO_SILK
LED1, LED2, LED3, LED4, LED5, LED6, LED7, LED8, LED9, LED10: LED5MM
R1, R2, R3, R4, R5, R6, R7, R8, R9, R10: 0207/7

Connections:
unnamed: LED2.A, R2.2
unnamed: J2.2, LED3.K, LED4.K
unnamed: LED1.A, R1.2
unnamed: J1.2, LED1.K, LED2.K
unnamed: J1.3, R1.1
unnamed: J1.1, R2.1
unnamed: J2.3, R3.1
unnamed: J2.1, R4.1
unnamed: LED4.A, R4.2
unnamed: LED3.A, R3.2
unnamed: J3.2, LED5.K, LED6.K
unnamed: J3.3, R5.1
unnamed: J3.1, R6.1
unnamed: LED6.A, R6.2
unnamed: LED5.A, R5.2
unnamed: J4.2, LED7.K, LED8.K
unnamed: J4.3, R7.1
unnamed: J4.1, R8.1
unnamed: LED8.A, R8.2
unnamed: LED7.A, R7.2
unnamed: J5.2, LED9.K, LED10.K
unnamed: J5.3, R9.1
unnamed: J5.1, R10.1
unnamed: LED10.A, R10.2
unnamed: LED9.A, R9.2

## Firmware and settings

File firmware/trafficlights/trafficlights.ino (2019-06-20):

/*
   Traffic Lights kit firmware

   The Cave, 2019
   https://thecave.cz

   Licensed under MIT License (see LICENSE file for details)

   Board: Arduino Nano
   Processor: ATmega328p

   Using TaskScheduler and OneButton libraries

*/
#include <OneButton.h>
#include <TaskScheduler.h>

#define PIN_BTN1 A1
#define PIN_BTN2 A2
#define PIN_BTN3 2

#define PIN_CAR_RED1 10
#define PIN_CAR_YELLOW1 12
#define PIN_CAR_GREEN1 11

#define PIN_CAR_RED2 6
#define PIN_CAR_YELLOW2 5
#define PIN_CAR_GREEN2 7

#define PIN_WALK_RED1 3
#define PIN_WALK_GREEN1 4

#define PIN_WALK_RED2 9
#define PIN_WALK_GREEN2 8


#define SIG_CAR_RED 0b00100
#define SIG_CAR_YELLOW 0b00010
#define SIG_CAR_GREEN 0b00001
#define SIG_WALK_RED 0b10000
#define SIG_WALK_GREEN 0b01000

#define SIG_SPEEDUP 0b00100000
#define SIG_TURNOFF 0b01000000
#define SIG_WALK    0b10000000


void keep_me_here() {}

Scheduler scheduler;
Task signalTask(1000, TASK_FOREVER, &signalWorkCb, &scheduler,  true);
uint8_t signalPos;
uint8_t signalRepeats;
uint8_t signalCurrent;
bool signalTurnOffFlag;
OneButton buttonWalk(PIN_BTN1, true);
OneButton buttonTurnOff(PIN_BTN3, true);


const uint8_t signalProgram[] PROGMEM = {
  SIG_WALK_RED | SIG_CAR_YELLOW | SIG_TURNOFF, 2,
  SIG_WALK_RED | SIG_CAR_RED, 2,
  SIG_WALK_GREEN | SIG_CAR_RED | SIG_SPEEDUP, 5 ,
  SIG_WALK_RED | SIG_CAR_RED, 2,
  SIG_WALK_RED | SIG_CAR_RED | SIG_CAR_YELLOW | SIG_TURNOFF, 2,
  SIG_WALK_RED | SIG_CAR_GREEN | SIG_SPEEDUP | SIG_WALK, 20,

  0, 0
};


void signalSet(const uint8_t s) {
  digitalWrite(PIN_WALK_RED1, s & SIG_WALK_RED);
  digitalWrite(PIN_WALK_RED2, s & SIG_WALK_RED);

  digitalWrite(PIN_WALK_GREEN1, s & SIG_WALK_GREEN);
  digitalWrite(PIN_WALK_GREEN2, s & SIG_WALK_GREEN);

  digitalWrite(PIN_CAR_RED1, s & SIG_CAR_RED);
  digitalWrite(PIN_CAR_RED2, s & SIG_CAR_RED);

  digitalWrite(PIN_CAR_YELLOW1, s & SIG_CAR_YELLOW);
  digitalWrite(PIN_CAR_YELLOW2, s & SIG_CAR_YELLOW);

  digitalWrite(PIN_CAR_GREEN1, s & SIG_CAR_GREEN);
  digitalWrite(PIN_CAR_GREEN2, s & SIG_CAR_GREEN);
}

void signalAdvance() {
  if (signalTurnOffFlag && (signalCurrent & SIG_TURNOFF)) {
    signalTurnOffFlag = false;
    signalCurrent = 0;
    signalTask.setCallback(signalBlinkCb);
    signalTask.enable();
    return;
  }
  signalPos++;

  signalCurrent = pgm_read_byte(signalProgram + signalPos * 2);
  signalRepeats = pgm_read_byte(signalProgram + signalPos * 2 + 1);

  signalSet(signalCurrent);
  if (signalRepeats == 0) {
    signalPos = 0xff;
    signalAdvance();
  }
}

void signalWorkCb() {
  if (signalRepeats == 0) {
    signalAdvance();
  }
  signalRepeats--;
}

void signalBlinkCb() {
  signalSet(signalTask.getRunCounter() & 1 ? 0 : SIG_CAR_YELLOW);
  if (signalTurnOffFlag) {
    signalTurnOffFlag = false;
    signalRepeats = 0;
    signalPos = 0xff;
    signalTask.setCallback(signalWorkCb);
    signalTask.enable();
  }
}

void buttonWalkClick() {
  if (signalCurrent & SIG_WALK) {
    signalAdvance();
  }
}

void buttonTurnOffClick() {
  signalTurnOffFlag = true;
  if (signalCurrent & SIG_SPEEDUP) {
    signalAdvance();
  }
}

void setup() {
  signalPos = 0;

  pinMode(PIN_WALK_RED1, OUTPUT);
  pinMode(PIN_WALK_RED2, OUTPUT);
  pinMode(PIN_WALK_GREEN1, OUTPUT);
  pinMode(PIN_WALK_GREEN2, OUTPUT);
  pinMode(PIN_CAR_RED1, OUTPUT);
  pinMode(PIN_CAR_RED2, OUTPUT);
  pinMode(PIN_CAR_YELLOW1, OUTPUT);
  pinMode(PIN_CAR_YELLOW2, OUTPUT);
  pinMode(PIN_CAR_GREEN1, OUTPUT);
  pinMode(PIN_CAR_GREEN2, OUTPUT);

  buttonWalk.attachClick(buttonWalkClick);
  buttonTurnOff.attachClick(buttonTurnOffClick);

  signalPos = 0xff;
  signalAdvance();
}

void loop() {
  buttonWalk.tick();
  buttonTurnOff.tick();
  scheduler.execute();
}

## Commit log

2019-05-14 Add pcbs
    [semafor-a-panel.brd, semafor-a.brd, semafor-a.sch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]
2019-06-20 Add missing ground wire to PCB and update gerbers
    [semafor-b-panel.brd]
2019-11-28 Add power switch and external voltage supply pins
    [semafor-a-r2.brd, semafor-a-r2.sch]
2019-12-05 Add panel for semafor-a-r2
    [semafor-a-r2-panel.brd]

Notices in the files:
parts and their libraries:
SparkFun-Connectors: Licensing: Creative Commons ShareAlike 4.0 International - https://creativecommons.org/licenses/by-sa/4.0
